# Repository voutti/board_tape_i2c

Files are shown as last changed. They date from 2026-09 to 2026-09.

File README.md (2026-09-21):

Commodore 64 I2C breakout/adapter -board for cassette port.
* 5V side and 3.3V side. Ground is common on both.
* External passthrough for powering 5V devices
* Board has a place for a fuse. It is up to you to decide what kind of fuse you end up using  (100mA, for example).
  It is probably a good idea to do some current calculations before adding too many devices.

Note 1: v0.1 requires that JP1 solder jumper is soldered (adds pull-up for SCLK on 5V side of the board).

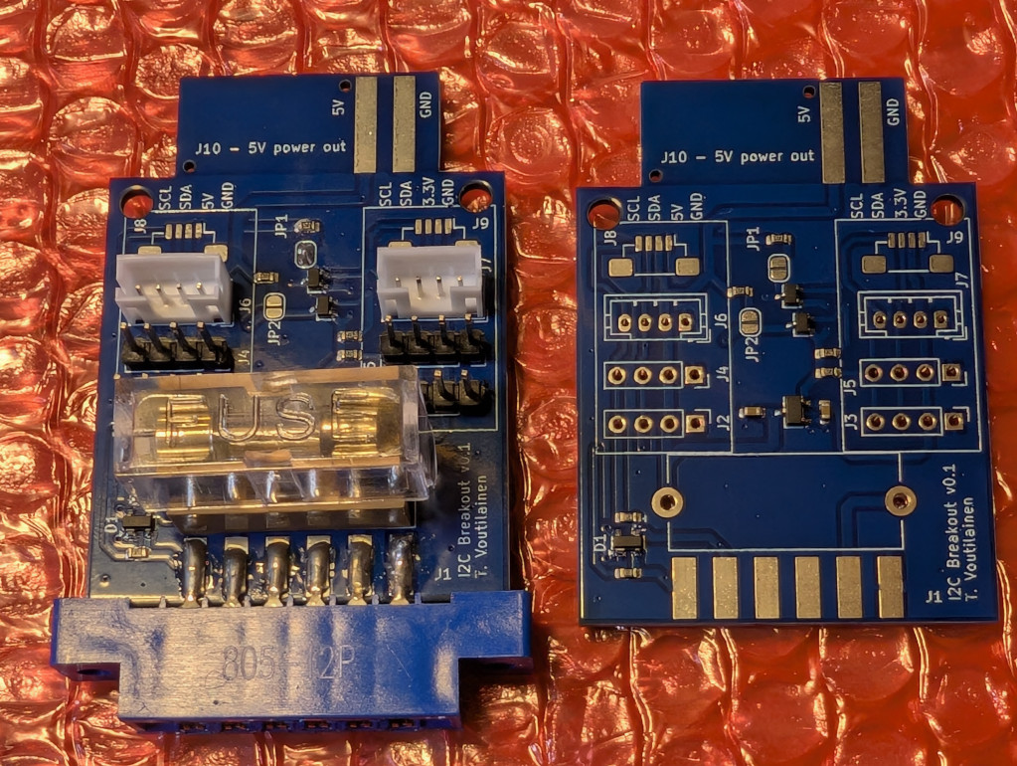
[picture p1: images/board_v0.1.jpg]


Note 2: Board assumes that in the SW driver - cassette port SENSE line is SDA and WRITE is SCL.
        It might be better if it was the other way around since SENSE line in Commodore 64 has a
        pretty strong 3.3kOhm pull-up and any I2C slave device needs to be able to sink enough current
        to pull it low enough to be seen as logic 0. If SENSE line would be used for SCL then the strong
        pull-up would not be a problem since SCL is (usually) only controlled by I2C master. For SDA
        we could decide our own pull-up resistor value - like 4.7kOhm or 10kOhm (4.7kOhm in v0.1 board).

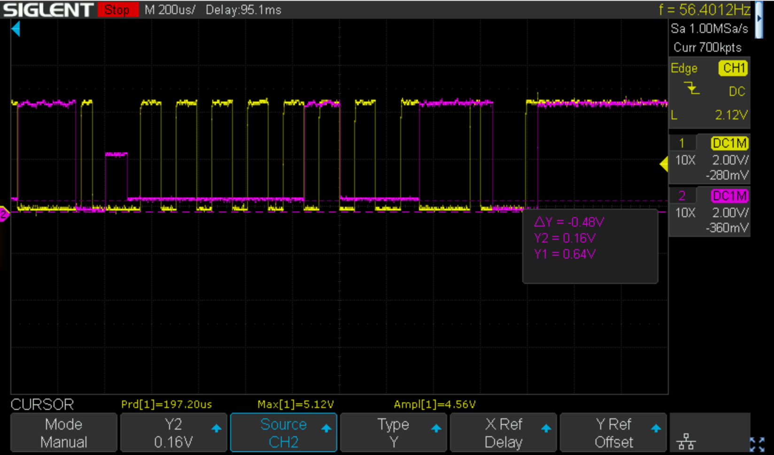
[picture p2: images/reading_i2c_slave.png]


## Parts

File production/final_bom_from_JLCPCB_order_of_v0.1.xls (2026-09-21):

Comment | Designator | Footprint | JLCPCB Part # | Qty | Ext.Price($)
BSS138W | Q1,Q2 | Q_SOT-323 | C28646265 | 14 | 0.35
1uF | C1,C2 | C_0603 | C15849 | 10 | 0.21
4k7 | R1,R2,R3,R4 | R_0603 | C23162 | 20 | 0.06
PRTR5V0U2X | D1 | SOT-143 | C2827688 | 9 | 0.60
XC6206P332MR | U1 | SOT-23-3_L2.9-W1.6-P1.90-LS2.8-BR | C5446 | 5 | 0.73
75 | R7,R8 | R_0603 | C4275 | 10 | 0.04

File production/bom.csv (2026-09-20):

Designator | Footprint | Quantity | Value | LCSC Part #
C1, C2 | C_0603 | 2 | 1uF
D1 | SOT-143 | 1 | PRTR5V0U2X
F1 | Fuseholder_Cylinder-5x20mm_Stelvio-Kontek_PTF78_Horizontal_Open | 1 | Fuse
J1 | C64-Cassette-Port-Female | 1 | C64-CassettePort
J10 - 5V POWER OUT | C64-Cassette-Port-Male | 1 | Power for external devices
J2, J3 | PinHeader_1x04_P2.54mm_Vertical | 2 | Conn_01x04_Socket
J4, J5 | PinSocket_1x04_P2.54mm_Vertical | 2 | Conn_01x04_Socket
J6, J7 | JST_PH_B4B-PH-K_1x04_P2.00mm_Vertical | 2 | Conn_01x04
J8, J9 | JST_SH_BM04B-SRSS-TB_1x04-1MP_P1.00mm_Vertical | 2 | Conn_01x04
Q1, Q2 | Q_SOT-323 | 2 | BSS138W | C28646265
R1, R2, R3, R4 | R_0603 | 4 | 4k7
R7, R8 | R_0603 | 2 | 75
U1 | SOT-23-3_L2.9-W1.6-P1.90-LS2.8-BR | 1 | XC6206P332MR | C5446

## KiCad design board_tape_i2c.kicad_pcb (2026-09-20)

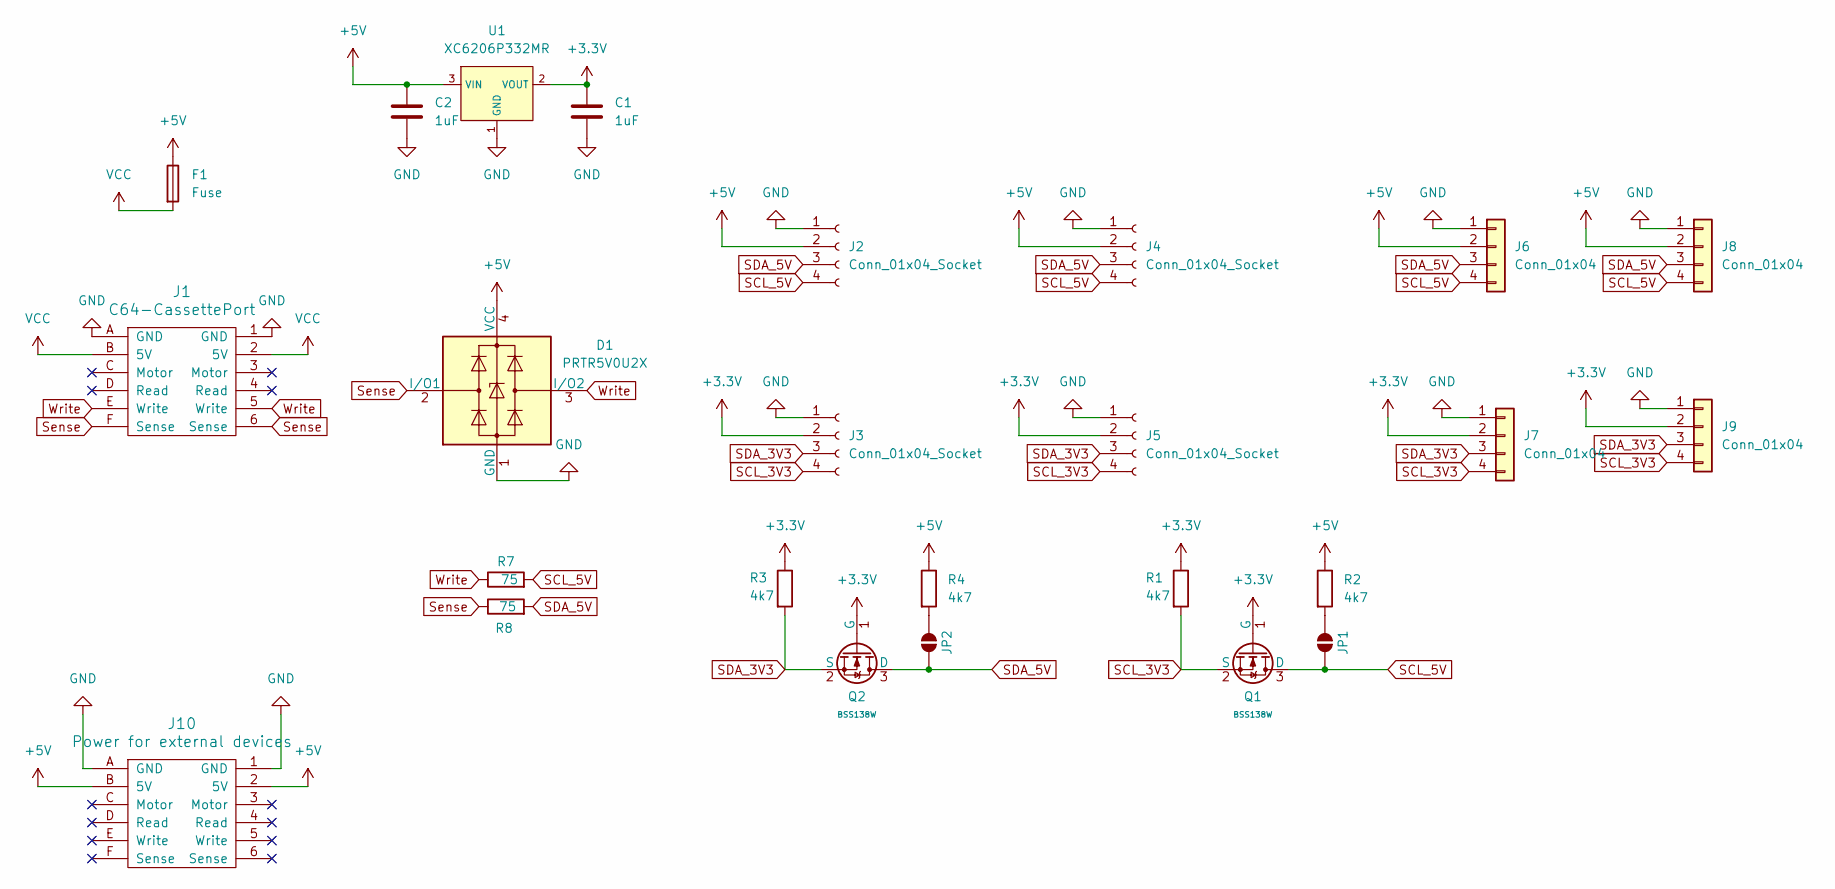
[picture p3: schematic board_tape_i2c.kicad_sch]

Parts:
C1, C2: 1uF; C_0603
D1: PRTR5V0U2X; SOT-143
F1: Fuse; Fuseholder_Cylinder-5x20mm_Stelvio-Kontek_PTF78_Horizontal_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
J1: C64-CassettePort; C64-Cassette-Port-Female
J2, J3: Conn_01x04_Socket; PinHeader_1x04_P2.54mm_Vertical
J4, J5: Conn_01x04_Socket; PinSocket_1x04_P2.54mm_Vertical
J6, J7: Conn_01x04; JST_PH_B4B-PH-K_1x04_P2.00mm_Vertical
J8, J9: Conn_01x04; JST_SH_BM04B-SRSS-TB_1x04-1MP_P1.00mm_Vertical
J10: Power for external devices; C64-Cassette-Port-Male
JP1, JP2: SolderJumper_2_Open; SolderJumper-2_P1.3mm_Open_RoundedPad1.0x1.5mm
Q1, Q2: BSS138W; Q_SOT-323; Part BSS138W; LCSC C28646265
R1, R2, R3, R4: 4k7; R_0603
R7, R8: 75; R_0603
U1: XC6206P332MR; SOT-23-3_L2.9-W1.6-P1.90-LS2.8-BR; Output Voltage 3.3V; Dropout Voltage 680mV@(100mA); Part XC6206P332MR-G; LCSC C5446

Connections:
+3.3V: C1.1, J3.2, J5.2, J7.2, J9.2, Q1.1 (G), Q2.1 (G), R1.1, R3.1, U1.2 (VOUT)
+5V: C2.1, D1.4 (VCC), F1.1, J2.2, J4.2, J6.2, J8.2, J10.2 (5V), J10.B (5V), R2.1, R4.1, U1.3 (VIN); also elsewhere on the board
GND: C1.2, C2.2, D1.1 (GND), J1.1 (GND), J1.A (GND), J2.1, J3.1, J4.1, J5.1, J6.1, J7.1, J8.1, J9.1, J10.1 (GND), J10.A (GND), U1.1 (GND); also elsewhere on the board
unnamed: JP1.2 (B), R2.2
unnamed: JP2.2 (B), R4.2
SCL_3V3: J3.4, J5.4, J7.4, J9.4, Q1.2 (S), R1.2
SCL_5V: J2.4, J4.4, J6.4, J8.4, JP1.1 (A), Q1.3 (D), R7.2
SDA_3V3: J3.3, J5.3, J7.3, J9.3, Q2.2 (S), R3.2
SDA_5V: J2.3, J4.3, J6.3, J8.3, JP2.1 (A), Q2.3 (D), R8.2
Sense: D1.2 (I/O1), J1.6 (Sense), J1.F (Sense), R8.1
VCC: F1.2, J1.2 (5V), J1.B (5V)
Write: D1.3 (I/O2), J1.5 (Write), J1.E (Write), R7.1

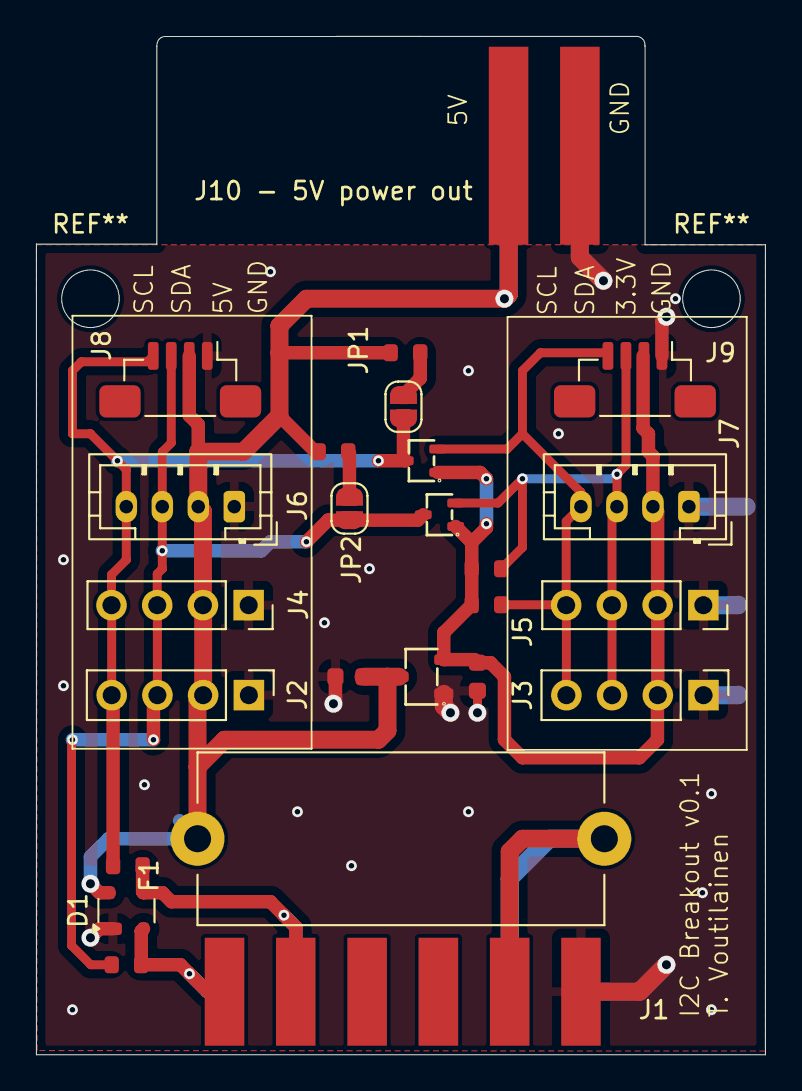
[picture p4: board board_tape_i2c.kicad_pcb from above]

Board: 2 copper layers, 40.5 x 56.6 mm, 25 parts (0 on the bottom side), 12 nets.

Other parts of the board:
J10 - 5V power out: Power for external devices; C64-Cassette-Port-Male

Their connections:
+5V: J10 - 5V power out.2 (5V), J10 - 5V power out.B (5V); also elsewhere on the board
GND: J10 - 5V power out.1 (GND), J10 - 5V power out.A (GND); also elsewhere on the board

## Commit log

2026-09-20 0.1 version added
    [board_tape_i2c.kicad_pcb, board_tape_i2c.kicad_sch, bom.csv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]
2026-09-21 Added final BOM of JLCPCB order of v0.1 board
    [final_bom_from_JLCPCB_order_of_v0.1.xls]
2026-09-21 Added v0.1 board image
2026-09-21 Added I2C slave reading scope capture
